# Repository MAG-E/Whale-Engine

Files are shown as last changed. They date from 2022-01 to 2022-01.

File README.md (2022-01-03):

# Whale-Engine
CMOS based optical drone synthesiser

Youtube video: https://youtu.be/fdHDt4L-P9A

Everything you need to build one of these is included. This is not a 'true' beginner project, some mechanical and electrical skills are required.
Some assumptions will need to be made with drilling and wiring the output jack and power input jack.
The PCB files are formatted for JLC manufacture. The original PCB was hand etched so the schematic includes jumpers. These can be ignored if you
order a PCB.

The finished device draws 50mA at most, making it suitable for battery or USB power. Do not connect more than 9V, the zener diode regulation is very crude.
The output is not suitable for powering headphones and benefits from being connected to an amplifier. It is designed to be connected to an amplified speaker.

Known issues:
- Even with modulation switches set to off, the modulations oscillators have an effect on the primary oscillator.
  This could be fixed by using a separate 4093 IC for the modulation oscillators. In one unit, I isolated the LEDs with
  a transistor and the issue was still there. 
  The problem is only with a TI CD4093, the now obsolete OnSemi CD4093s I have do not exhibit this.
  This isn't a refined product, it was built for kids christmas presents.
  
MAG-03/01/2022

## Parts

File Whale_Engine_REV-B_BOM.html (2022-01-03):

 |  | WHALE ENGINE REV: B
 |  | BILL OF MATERIALS | MAG - DEC 2021
QTY | VALUE | DESIGNATOR | TYPE | SIZE
 | RESISTOR
2 | 1K | R1, R2 | R-EU_0204/7 | 0204/7
1 | 2k | R9 | R-EU_0204/7 | 0204/7
1 | 3K3 | R19 | R-EU_0204/7 | 0204/7
1 | 4.7K | R13 | R-EU_0204/7 | 0204/7
1 | 5.6K | R8 | R-EU_0204/7 | 0204/7
4 | 10k | R5, R6, R10, R12 | R-EU_0204/7 | 0204/7
2 | 15K | R7, R14 | R-EU_0204/7 | 0204/7
1 | 18K | R11 | R-EU_0204/7 | 0204/7
2 | 22K | R3, R16 | R-EU_0204/7 | 0204/7
1 | 68k | R4 | R-EU_0204/7 | 0204/7
1 | 100K | R15 | R-EU_0204/7 | 0204/7
2 | 220K | R17, R18 | R-EU_0204/7 | 0204/7
 | CAPACITOR
2 | 560pF | C5, C6 | C2.5/2 | C2.5-2
1 | 10nF | C17 | C2.5/2 | C2.5-2
1 | 3.3nF | C9 | C2.5/2 | C2.5-2
2 | 82nF | C7, C8 | C2.5/2 | C2.5-2
1 | 100nF | C4 | C2.5/2 | C2.5/2
4 | 100nF | C10, C11, C19, C21 | C2.5/2 | C2.5-2
1 | 470nF | C1 | C7.5/3 | C7.5B3
1 | 4.7uF | C16 | CPOL-EUE2-5 | E2-5
4 | 10uF | C2, C14, C15, C20 | CPOL-EUE2-5 | E2-5
3 | 47uF | C3, C12, C13 | CPOL-EUE2-5 | E2-5
2 | 100uF | C18, C22 | CPOL-EUE2-5 | E2-5
 | SEMICONDUCTOR
1 | 2N3904 | T1 | 2N3904 | TO92
1 | 4093N | IC1 | 4093N | DIL14
1 | PT2399 | U1 | PT2399 | DIL16
 | OPTICAL
2 | GREEN LED | LED1, LED2 | LED5MM | LED5MM
2 | CDS PHOTOCELL | CDS1, CDS2 | CDS PHOTOCELL
 | HARDWARE
2 | 100KB | MOD1, MOD2 | ALPHA 9MM VERTICAL
1 | 5KB | MOD1_FINE
1 | 10KA | VOLUME
2 | 50KB | MIX, TIME
1 | 10KB | FEEDBACK
2 | 5MM LED MOUNT | FOR PANEL MOUNTING CDS CELLS
2 | SPDT_C&K_PCB | SWMOD1, SWMOD2 | SPDT_C&K_PCB | C&K_SPDT_PCB

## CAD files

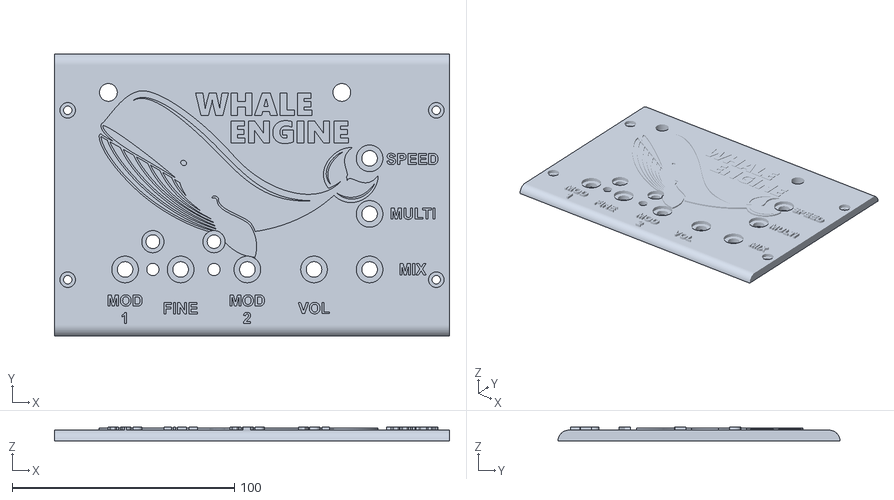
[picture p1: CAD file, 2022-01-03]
3D-PRINT/Whale_Engine-Control_Panel.stl
177.7 x 127.0 x 6.50

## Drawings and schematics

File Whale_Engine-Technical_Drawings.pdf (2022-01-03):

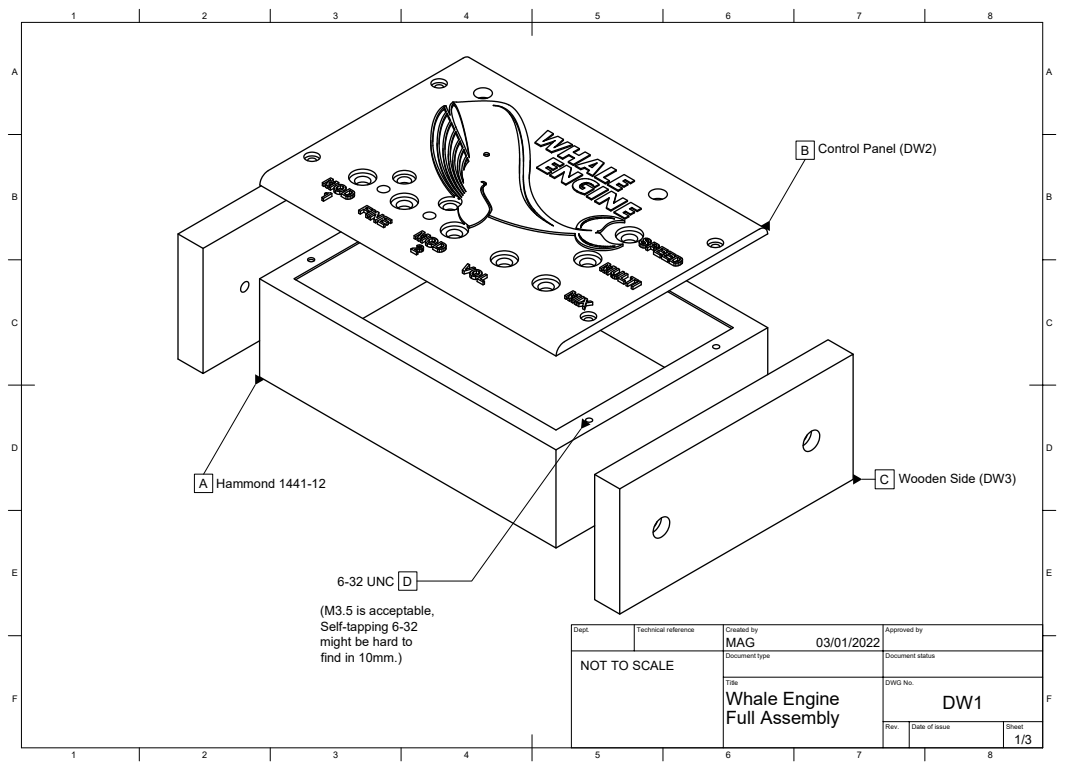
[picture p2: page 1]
8 BCDEF; ABCDEF Dept.; Technical reference; Created by; Approved by Document type; Document status Title; DWG No. Rev.; Date of issue; Sheet 03/01/2022; 1/3 Full Assembly Whale Engine; DW1 MAG A Hammond 1441-12; B Control Panel (DW2) 6-32 UNC D (M3.5 is acceptable, Self-tapping 6-32 might be hard to find in 10mm.); NOT TO SCALE; C Wooden Side (DW3)

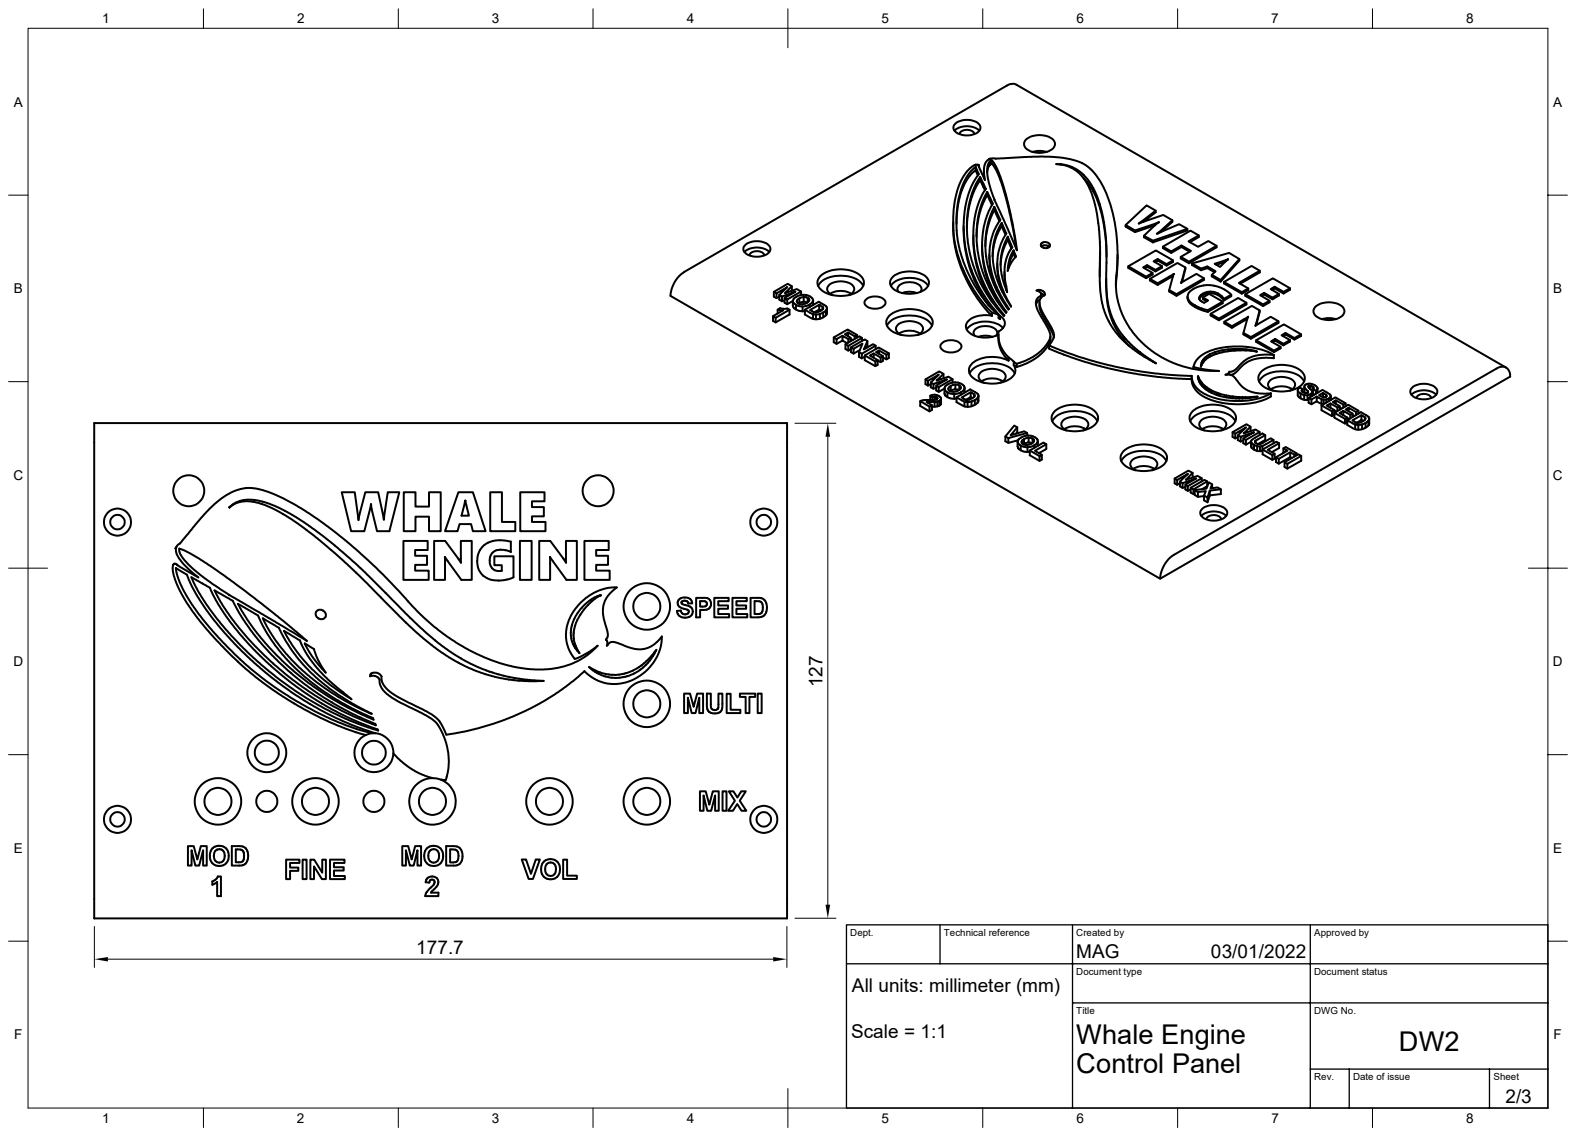
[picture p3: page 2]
8 BCDEF; ABCDEF Dept.; Technical reference; Created by; Approved by Document type; Document status Title; DWG No. Rev.; Date of issue; Sheet 03/01/2022; 2/3 Control Panel Whale Engine; DW2 ¹⁷⁷.7; MAG

127 All units: millimeter (mm) Scale = 1:1

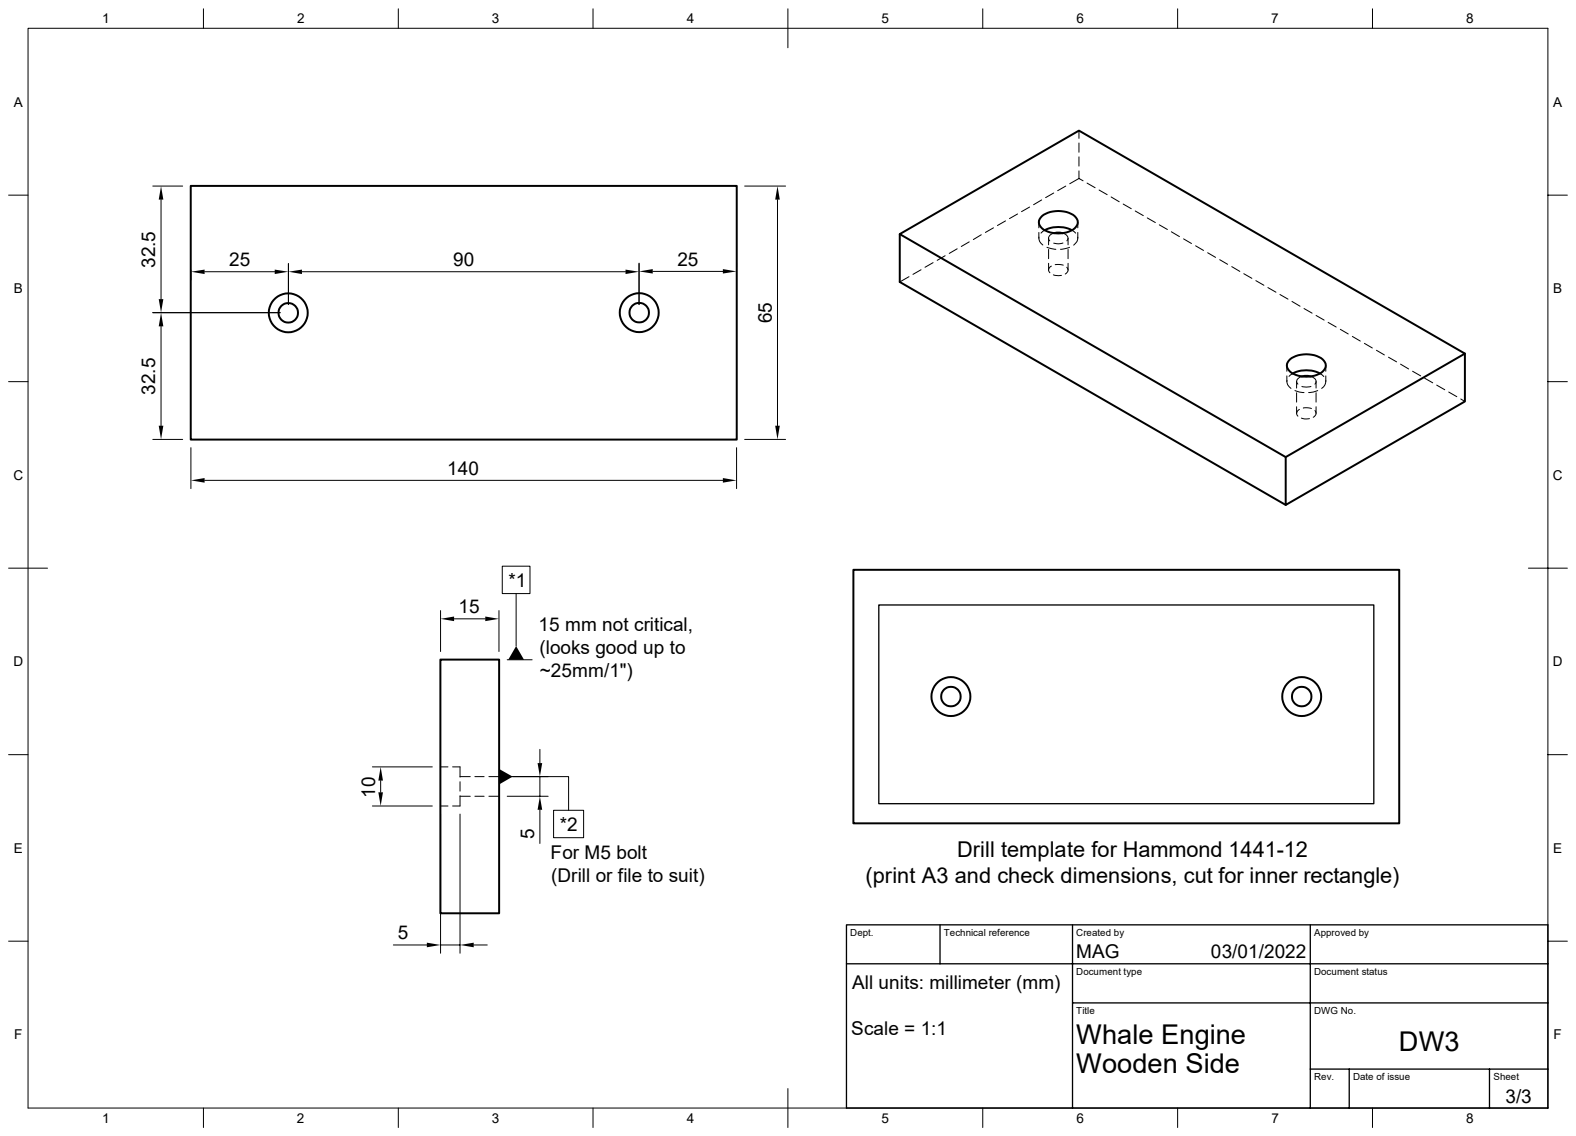
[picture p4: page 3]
8 BCDEF; ABCDEF Dept.; Technical reference; Created by; Approved by Document type; Document status Title; DWG No. Rev.; Date of issue; Sheet 03/01/2022; 3/3 Wooden Side Whale Engine; DW3 MAG 140

10 5 15 All units: millimeter (mm) Scale = 1:1 5 Drill template for Hammond 1441-12 (print A3 and check dimensions, cut for inner rectangle) 15 mm not critical, (looks good up to ~25mm/1") For M5 bolt (Drill or file to suit) *1 *2

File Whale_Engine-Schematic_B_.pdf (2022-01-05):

100nF | 100uF 68k 22K
C21 | C22 R⁴ R¹⁶

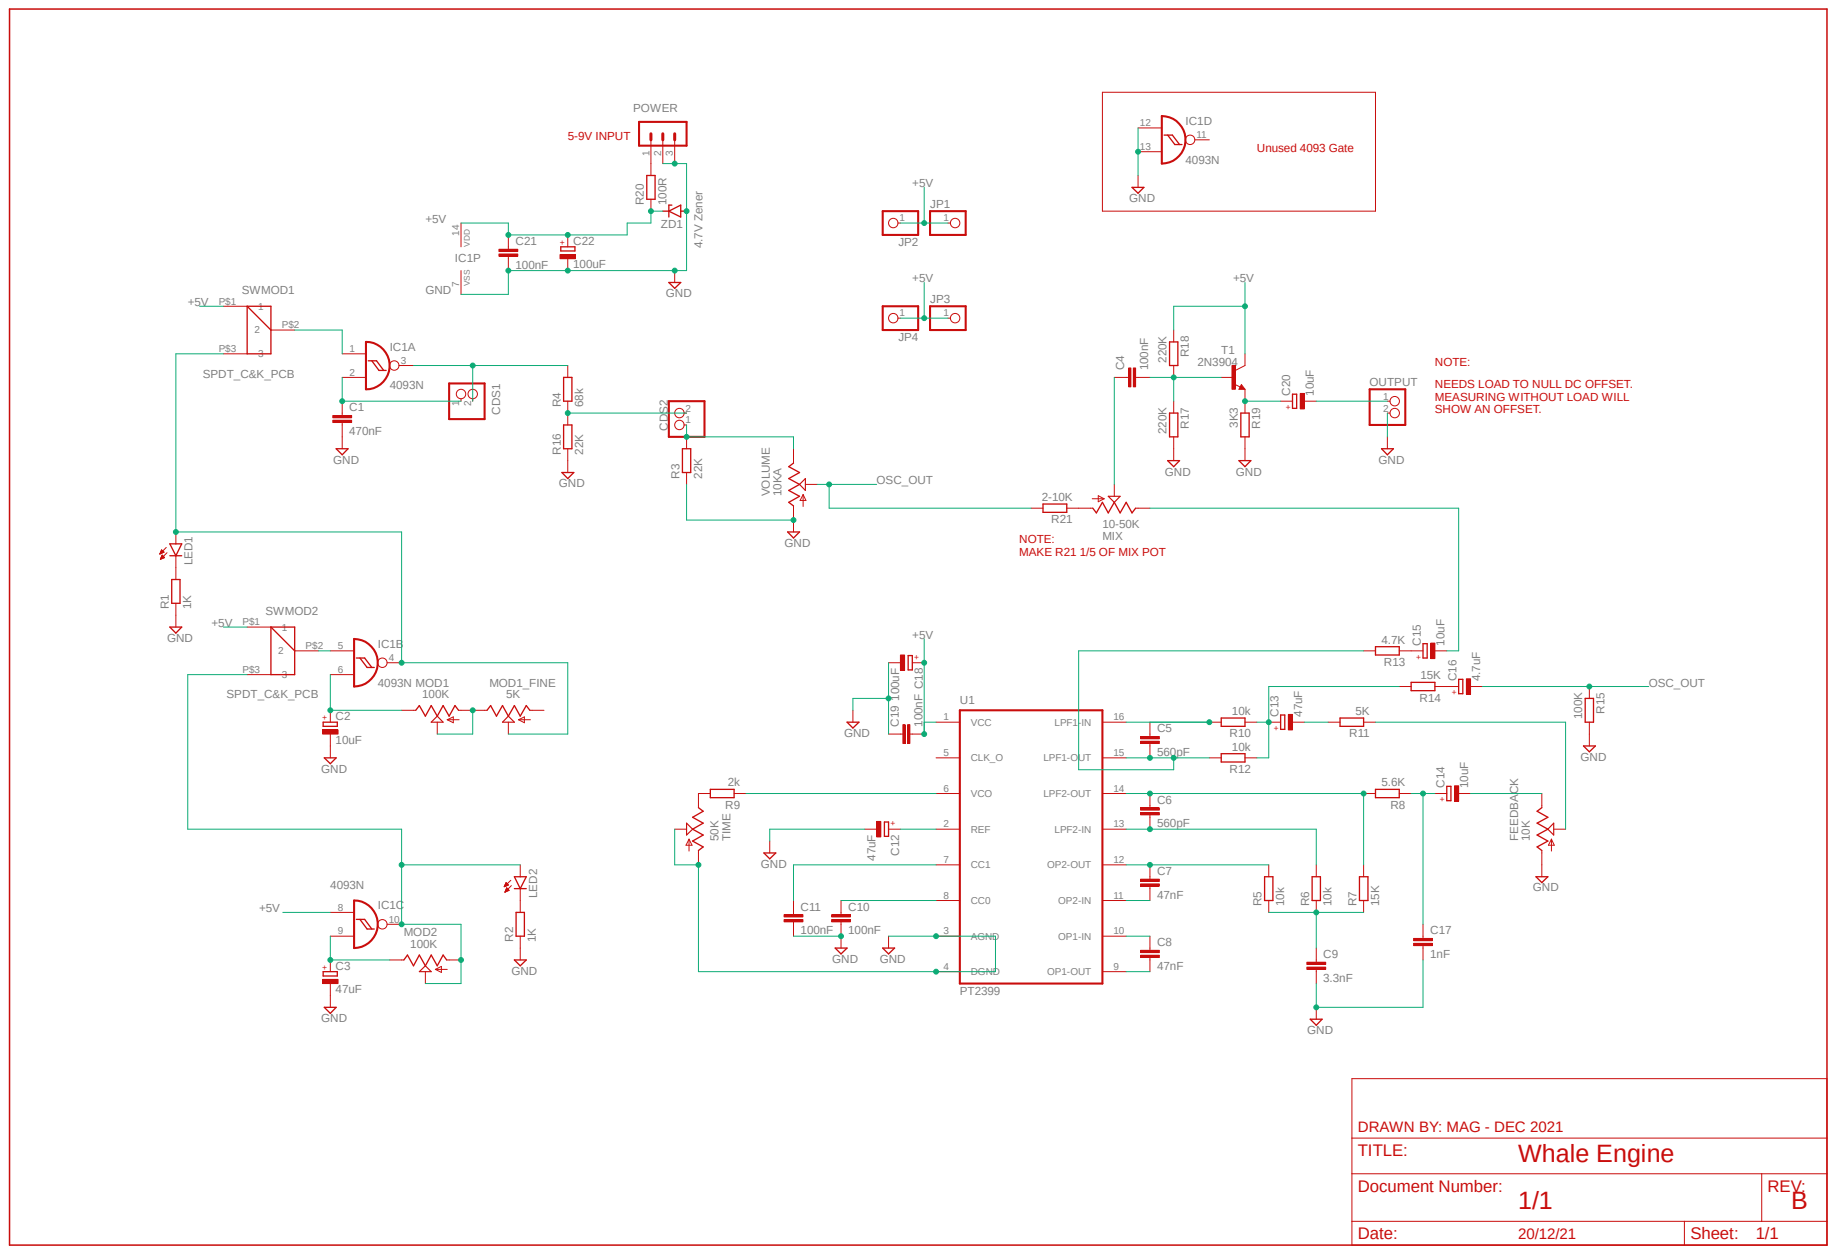
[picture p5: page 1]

OUTPUT C¹⁸ C¹⁹ VDD 7 14 VSS

NOTE:
NEEDS LOAD TO NULL DC OFFSET.
MEASURING WITHOUT LOAD WILL
SHOW AN OFFSET.

DRAWN BY: MAG - DEC 2021
TITLE:

Document Number: 1/1 | REV: B

Date: 20/12/21 | Sheet: 1/1

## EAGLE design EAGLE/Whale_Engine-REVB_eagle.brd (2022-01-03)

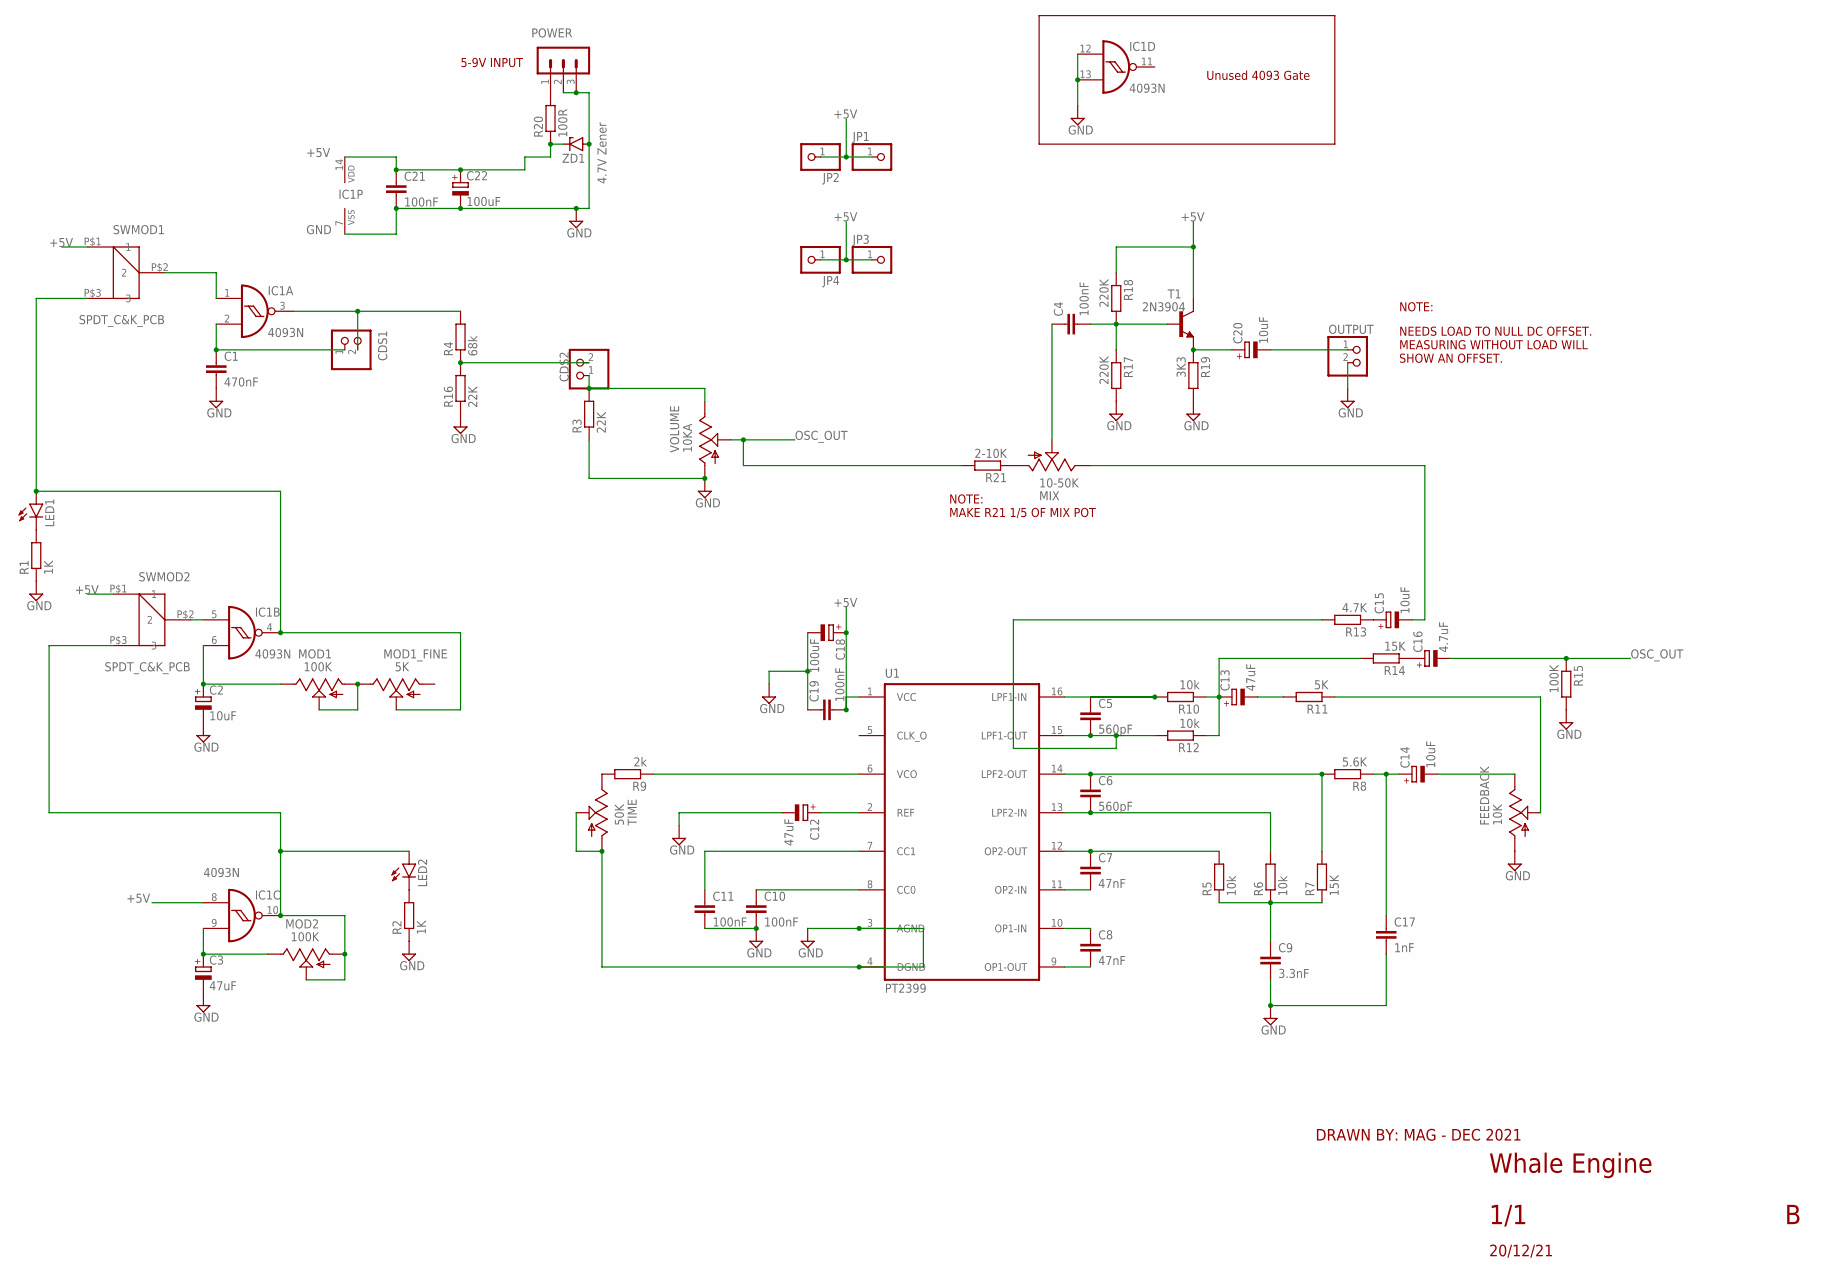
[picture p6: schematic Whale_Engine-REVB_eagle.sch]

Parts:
C1: 470nF; C7.5B3
C2, C14, C15, C20: 10uF; E2-5
C3, C12, C13: 47uF; E2-5
C4: 100nF; C050-025X075
C5, C6: 560pF; C2.5-2
C7, C8: 47nF; C2.5-2
C9: 3.3nF; C2.5-2
C10, C11, C19, C21: 100nF; C2.5-2
C16: 4.7uF; E2-5
C17: 1nF; C2.5-2
C18, C22: 100uF; E2-5
CDS1, CDS2: PINHD-1X2; 1X02
FEEDBACK: 10K; 9MM_SNAP-IN_POT
IC1: 4093N; DIL14
JP1, JP2, JP3, JP4: PINHD-1X1; 1X01
LED1, LED2: LED3MM
MIX: 10-50K; 9MM_SNAP-IN_POT
MOD1, MOD2: 100K; 9MM_SNAP-IN_POT
MOD1_FINE: 5K; 9MM_SNAP-IN_POT
OUTPUT: PINHD-1X2; 1X02
POWER: MA03-1
R1, R2: 1K; 0204/7
R3, R16: 22K; 0204/7
R4: 68k; 0204/7
R5, R6, R10, R12: 10k; 0204/7
R7, R14: 15K; 0204/7
R8: 5.6K; 0204/7
R9: 2k; 0204/7
R11: 5K; 0204/7
R13: 4.7K; 0204/7
R15: 100K; 0204/7
R17, R18: 220K; 0204/7
R19: 3K3; 0204/7
R20: 100R; 0204/7
R21: 2-10K; 0204/7
SWMOD1, SWMOD2: SPDT_C&K_PCB; C&K_SPDT_PCB
T1: 2N3904; TO92
TIME: 50K; 9MM_SNAP-IN_POT
U1: PT2399; DIL16
VOLUME: 10KA; 9MM_SNAP-IN_POT
ZD1: 4.7V Zener; SOD81

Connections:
+5V: C18.+, C19.2, C21.1, C22.+, IC1.8 (I0), IC1.14 (VDD), JP1.1, JP2.1, JP3.1, JP4.1, R18.1, R20.1, SWMOD1.P$1 (1), SWMOD2.P$1 (1), T1.1 (C), U1.1 (VCC), ZD1.C
GND: C1.2, C2.-, C3.-, C9.2, C10.2, C11.2, C12.-, C17.2, C18.-, C19.1, C21.2, C22.-, FEEDBACK.1 (A), IC1.7 (VSS), IC1.12 (I0), IC1.13 (I1), OUTPUT.2, POWER.2, POWER.3, R1.1, R2.1, R3.1, R15.2, R16.1, R17.2, R19.2, TIME.1 (A), TIME.2 (S), U1.3 (AGND), U1.4 (DGND), VOLUME.1 (A), ZD1.A
unnamed: IC1.1 (I0), SWMOD1.P$2 (2)
unnamed: IC1.5 (I0), SWMOD2.P$2 (2)
unnamed: C2.+, IC1.6 (I1), MOD1.3 (E)
unnamed: MOD1.1 (A), MOD1.2 (S), MOD1_FINE.3 (E)
unnamed: IC1.4 (O), LED1.A, MOD1_FINE.2 (S), SWMOD1.P$3 (3)
unnamed: IC1.10 (O), LED2.A, MOD2.1 (A), MOD2.2 (S), SWMOD2.P$3 (3)
unnamed: C1.1, CDS1.1, IC1.2 (I1)
unnamed: CDS1.2, IC1.3 (O), R4.2
unnamed: LED1.K (C), R1.2
unnamed: LED2.K (C), R2.2
unnamed: C3.+, IC1.9 (I1), MOD2.3 (E)
unnamed: CDS2.2, R4.1, R16.2
unnamed: CDS2.1, R3.2, VOLUME.3 (E)
unnamed: C5.1, R10.2, U1.16 (LPF1-IN)
unnamed: C5.2, R12.2, R13.2, U1.15 (LPF1-OUT)
unnamed: C6.1, R7.2, R8.2, U1.14 (LPF2-OUT)
unnamed: C6.2, R6.2, U1.13 (LPF2-IN)
unnamed: C7.1, R5.2, U1.12 (OP2-OUT)
unnamed: C7.2, U1.11 (OP2-IN)
unnamed: C8.1, U1.10 (OP1-IN)
unnamed: C8.2, U1.9 (OP1-OUT)
unnamed: C9.1, R5.1, R6.1, R7.1
unnamed: C10.1, U1.8 (CC0)
unnamed: C11.1, U1.7 (CC1)
unnamed: R9.1, U1.6 (VCO)
unnamed: R9.2, TIME.3 (E)
unnamed: C4.2, R17.1, R18.2, T1.2 (B)
unnamed: C12.+, U1.2 (REF)
unnamed: C13.+, R10.1, R12.1, R14.2
unnamed: C13.-, R11.2
unnamed: FEEDBACK.2 (S), R11.1
unnamed: C14.-, FEEDBACK.3 (E)
unnamed: C14.+, C17.1, R8.1
unnamed: C15.+, R13.1
unnamed: C4.1, MIX.2 (S)
unnamed: C16.+, R14.1
unnamed: C20.+, R19.1, T1.3 (E)
unnamed: C20.-, OUTPUT.1
unnamed: C15.-, MIX.3 (E)
unnamed: MIX.1 (A), R21.1
unnamed: POWER.1, R20.2
OSC_OUT: C16.-, R15.1, R21.2, VOLUME.2 (S)

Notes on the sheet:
5-9V INPUT
NOTE:
NEEDS LOAD TO NULL DC OFFSET. MEASURING WITHOUT LOAD WILL SHOW AN OFFSET.
Whale Engine
1/1
20/12/21
DRAWN BY: MAG - DEC 2021
NOTE: MAKE R21 1/5 OF MIX POT
Unused 4093 Gate

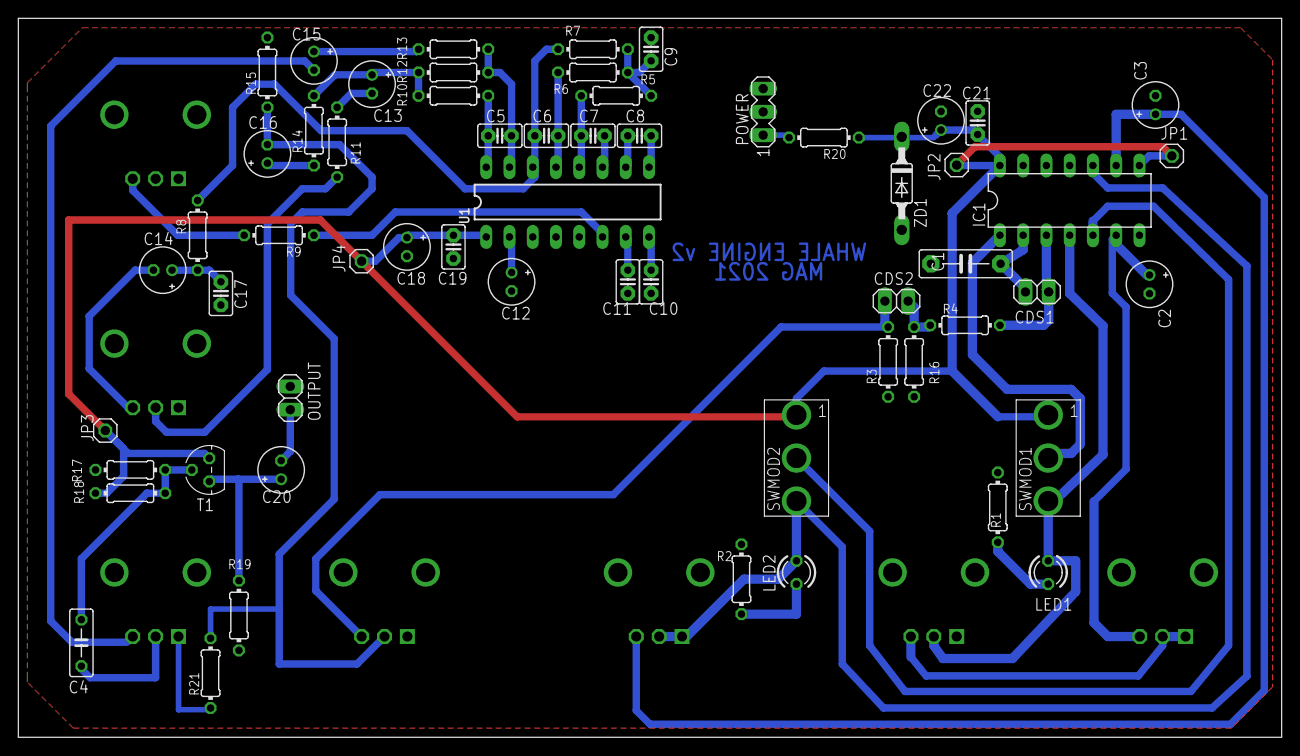
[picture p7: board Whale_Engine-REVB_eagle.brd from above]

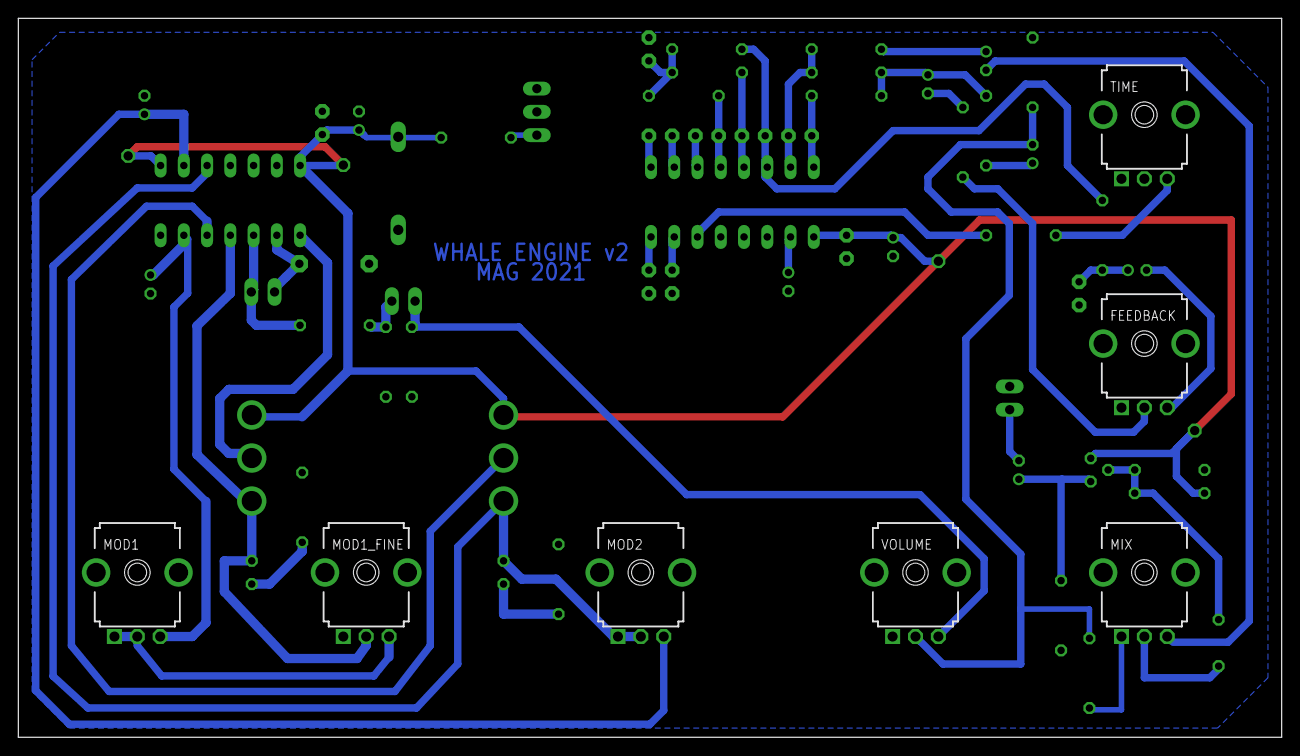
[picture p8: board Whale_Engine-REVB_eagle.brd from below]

Board: 2 copper layers, 138.0 x 78.5 mm, 66 parts (7 on the bottom side), 44 nets.

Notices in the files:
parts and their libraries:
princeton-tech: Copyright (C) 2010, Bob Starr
